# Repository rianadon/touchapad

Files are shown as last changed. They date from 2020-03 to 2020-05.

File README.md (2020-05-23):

# Touchapad

Touchapad is an touchscreen-based button pad designed to be placed outdoors and control [Home Assistant](https://home-assistant.io) devices.

This repository hosts the code used for:
 - The Arduino controlling the touchscreen
 - STL files for 3D-printed parts
 - KiCad files for the Arduino shield. You can download KiCad to export Gerber files configured to however your PCB manufacturer requires.
 - Python server for linking the Arduino touchscreen to Home Assistant and serving the configuration frontend
 - Configuration frontend source code (uses Svelte so you've got to compile it)

The Touchapad

Design and architecture information can be found at the project's [blog post](https://rianadon.github.io/blog/2020/05/23/touchapad.html).

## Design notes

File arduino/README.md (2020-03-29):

# Arduino Code

Code here is designed to run on an Arduino Leonardo (simply chosen becaue due to limited space, buying a slim USB cable for a micro-USB port was much easier than buying one for the bulky USB port of an Uno.

The excess of files is due to me having to modify the MCU and GFX libraries slim down the sketch size. They are missing a few lines of code compared to their original form. However, since they are in this repository, you don't have to install any external libraries!

## What are these Python files?

The files `corners.py` and `font.py` generate `corners.h` and `font.h` respectively. Both of these files exist because it is much easier to create anti-aliased text in Python and export it as bitmaps for the Arduino code to consume rather than try to perform the same computations on the Arduino. `corners.py` generates bitmaps for creating rectangles with rounded corners, and `font.py` generates bitmaps for a random font I found on my computer.

## Uploading

You can either upload the sketch using the Arduino IDE, or use

```bash
arduino-cli compile -u -b arduino:avr:leonardo -p /dev/ttyACM0 .
```

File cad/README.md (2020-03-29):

# Files to be 3D printed

You'll need one of each part, except for `standoff.stl` - you'll need three. They were designed to be printed in ABS, but PLA would probably work too.

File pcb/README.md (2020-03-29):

# PCB files

These files were generated using KiCad. You can use the same software to generate the gerbers and drill files, which I've omitted.

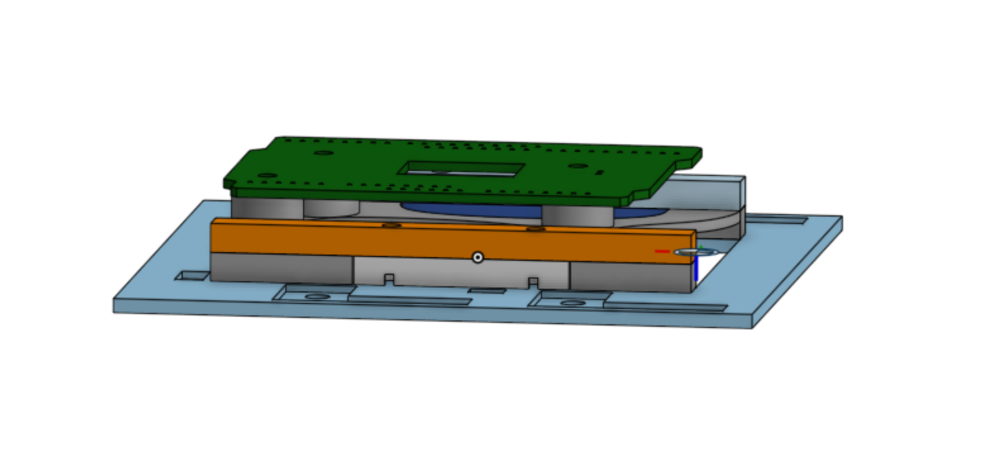
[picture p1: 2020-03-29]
cad/screenshot-2.png

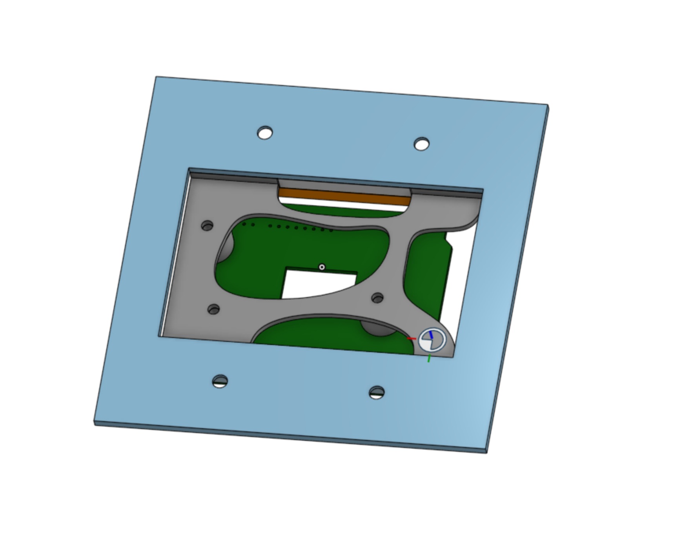
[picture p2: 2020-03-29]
cad/screenshot-1.png

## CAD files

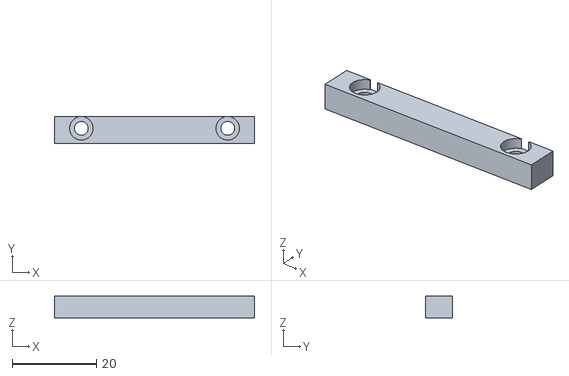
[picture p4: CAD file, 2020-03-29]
cad/holder1.stl
47.4 x 6.35 x 5.15

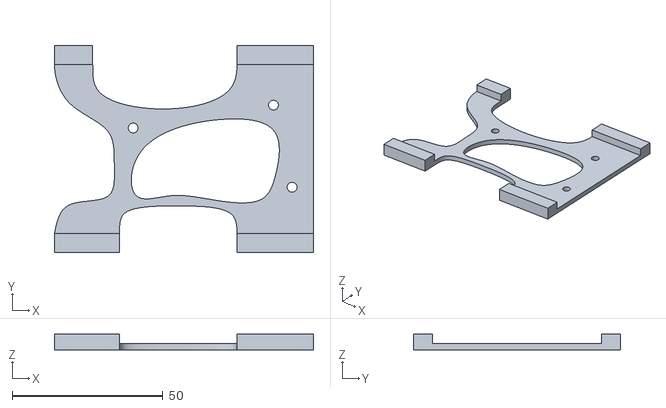
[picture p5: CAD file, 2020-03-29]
cad/arduinoholder.stl
86.0 x 68.7 x 5.15

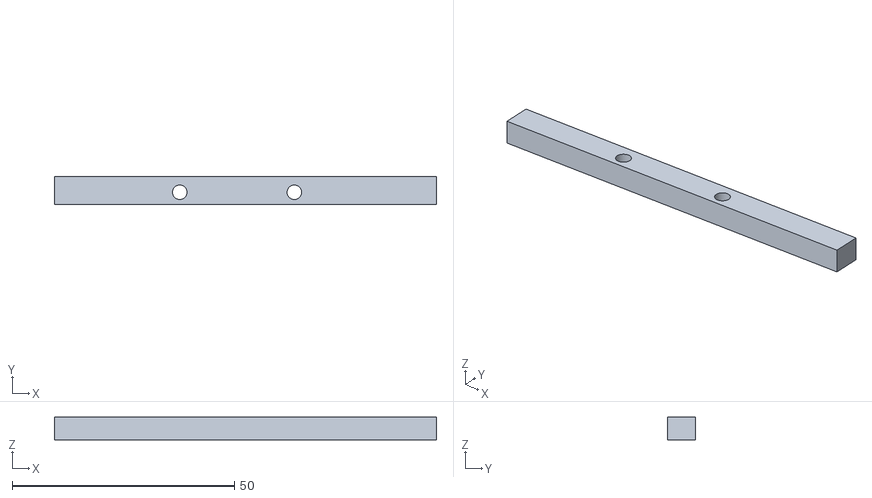
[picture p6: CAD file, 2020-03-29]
cad/holder4.stl
86.0 x 6.35 x 5.16

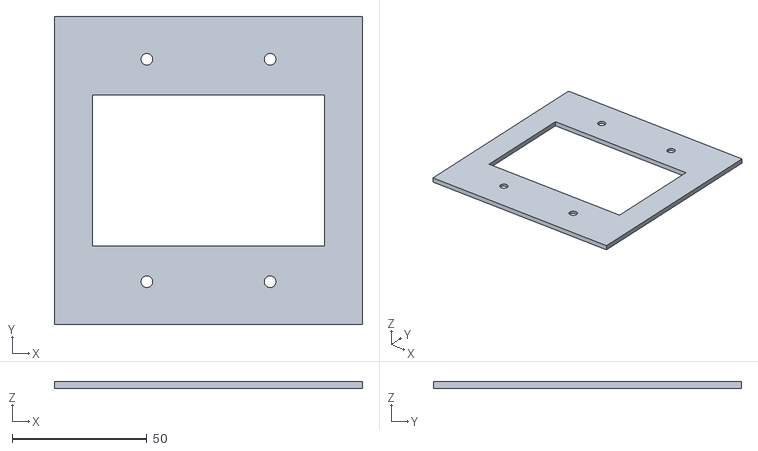
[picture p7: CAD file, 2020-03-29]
cad/cover.stl
114.3 x 114.3 x 2.50

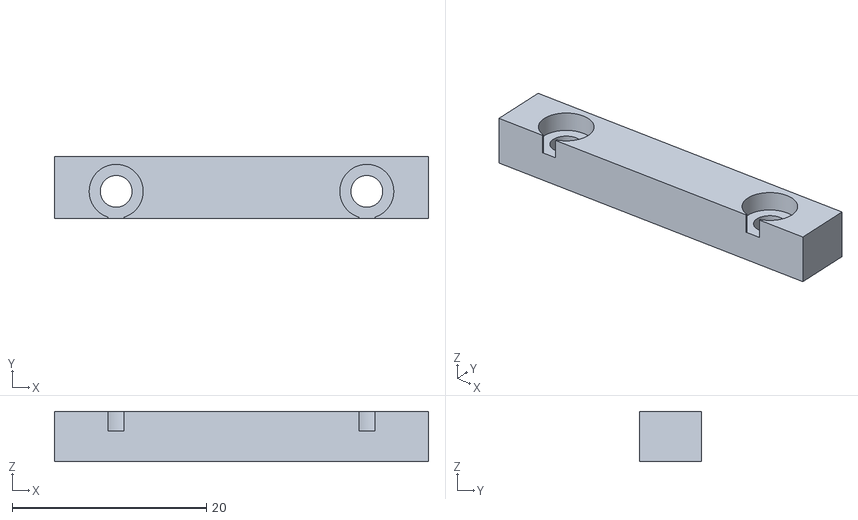
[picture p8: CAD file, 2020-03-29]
cad/holder2.stl
38.5 x 6.35 x 5.15

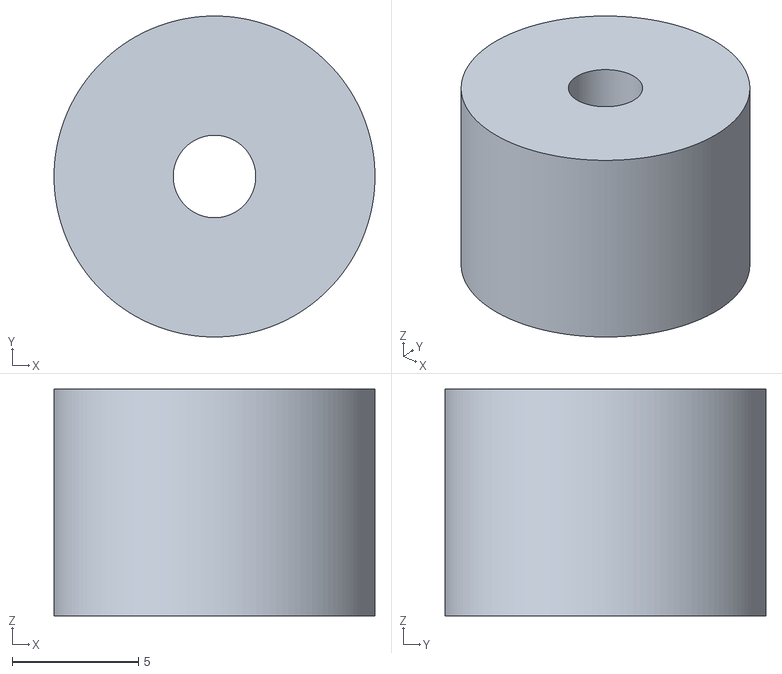
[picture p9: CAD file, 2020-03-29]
cad/standoff.stl
12.7 x 12.7 x 8.97

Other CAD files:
cad/holder3.stl

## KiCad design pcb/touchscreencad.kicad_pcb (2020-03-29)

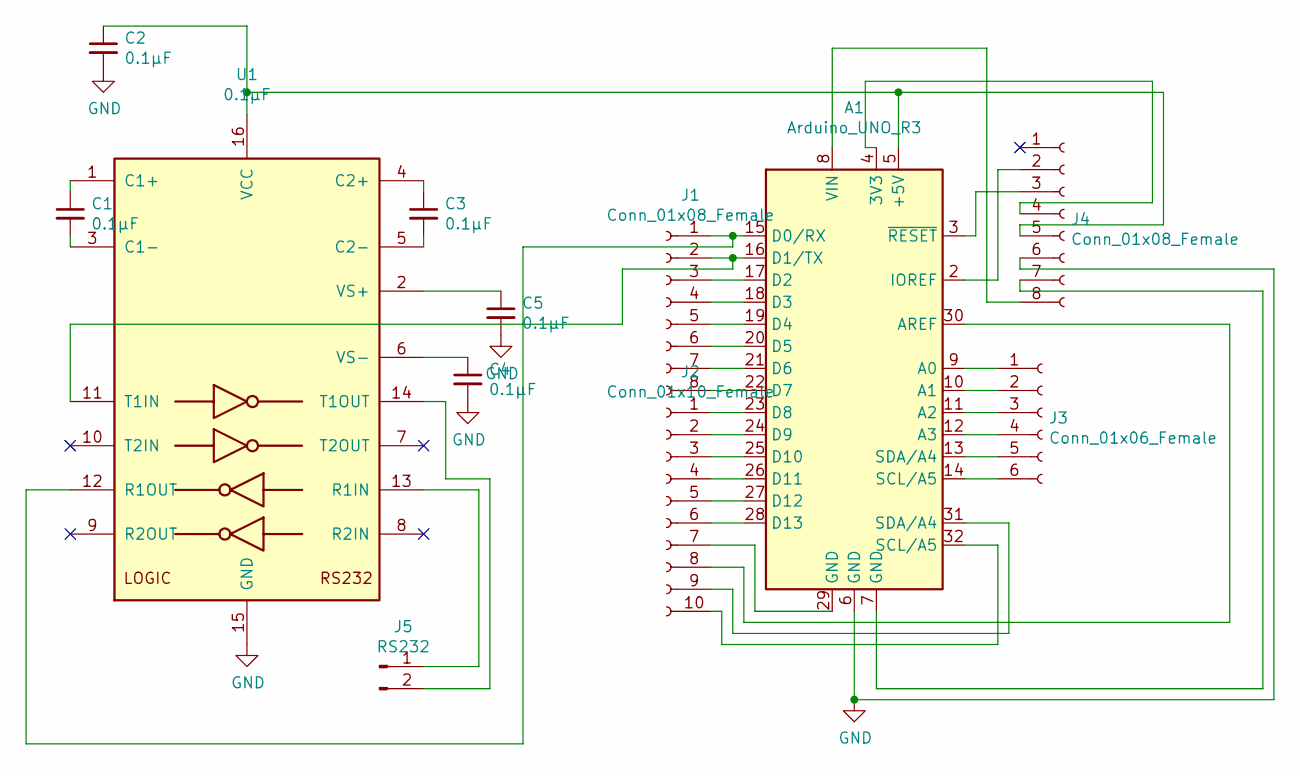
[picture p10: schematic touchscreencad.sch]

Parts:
A1: Arduino_UNO_R3
C1, C2, C3, C4, C5: 0.1μF; C_0402_1005Metric
J1: Conn_01x08_Female; PinHeader_1x08_P2.54mm_Vertical
J2: Conn_01x10_Female; PinHeader_1x10_P2.54mm_Vertical
J3: Conn_01x06_Female; PinHeader_1x06_P2.54mm_Vertical
J4: Conn_01x08_Female; PinSocket_1x08_P2.54mm_Vertical
J5: RS232; PinSocket_1x02_P2.54mm_Horizontal
U1: 0.1μF; SOIC-16_3.9x9.9mm_P1.27mm

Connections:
GND: A1.6 (GND), C2.2, C4.2, C5.2, J4.6, U1.15 (GND)
unnamed: A1.2 (IOREF), J4.2
unnamed: A1.3 (~RESET), J4.3
unnamed: A1.4 (3V3), J4.4
unnamed: A1.5 (+5V), C2.1, J4.5, U1.16 (VCC)
unnamed: A1.7 (GND), J4.7
unnamed: A1.8 (VIN), J4.8
unnamed: A1.9 (A0), J3.1
unnamed: A1.10 (A1), J3.2
unnamed: A1.11 (A2), J3.3
unnamed: A1.12 (A3), J3.4
unnamed: A1.13 (SDA/A4), J3.5
unnamed: A1.14 (SCL/A5), J3.6
unnamed: A1.15 (D0/RX), J1.1, U1.12 (R1OUT)
unnamed: A1.16 (D1/TX), J1.2, U1.11 (T1IN)
unnamed: A1.17 (D2), J1.3
unnamed: A1.18 (D3), J1.4
unnamed: A1.19 (D4), J1.5
unnamed: A1.20 (D5), J1.6
unnamed: A1.21 (D6), J1.7
unnamed: A1.22 (D7), J1.8
unnamed: A1.23 (D8), J2.1
unnamed: A1.24 (D9), J2.2
unnamed: A1.25 (D10), J2.3
unnamed: A1.26 (D11), J2.4
unnamed: A1.27 (D12), J2.5
unnamed: A1.28 (D13), J2.6
unnamed: A1.29 (GND), J2.7
unnamed: A1.30 (AREF), J2.8
unnamed: A1.31 (SDA/A4), J2.9
unnamed: A1.32 (SCL/A5), J2.10
unnamed: C1.1, U1.1 (C1+)
unnamed: C1.2, U1.3 (C1-)
unnamed: C3.1, U1.4 (C2+)
unnamed: C3.2, U1.5 (C2-)
unnamed: C4.1, U1.6 (VS-)
unnamed: C5.1, U1.2 (VS+)
unnamed: J5.1, U1.13 (R1IN)
unnamed: J5.2, U1.14 (T1OUT)

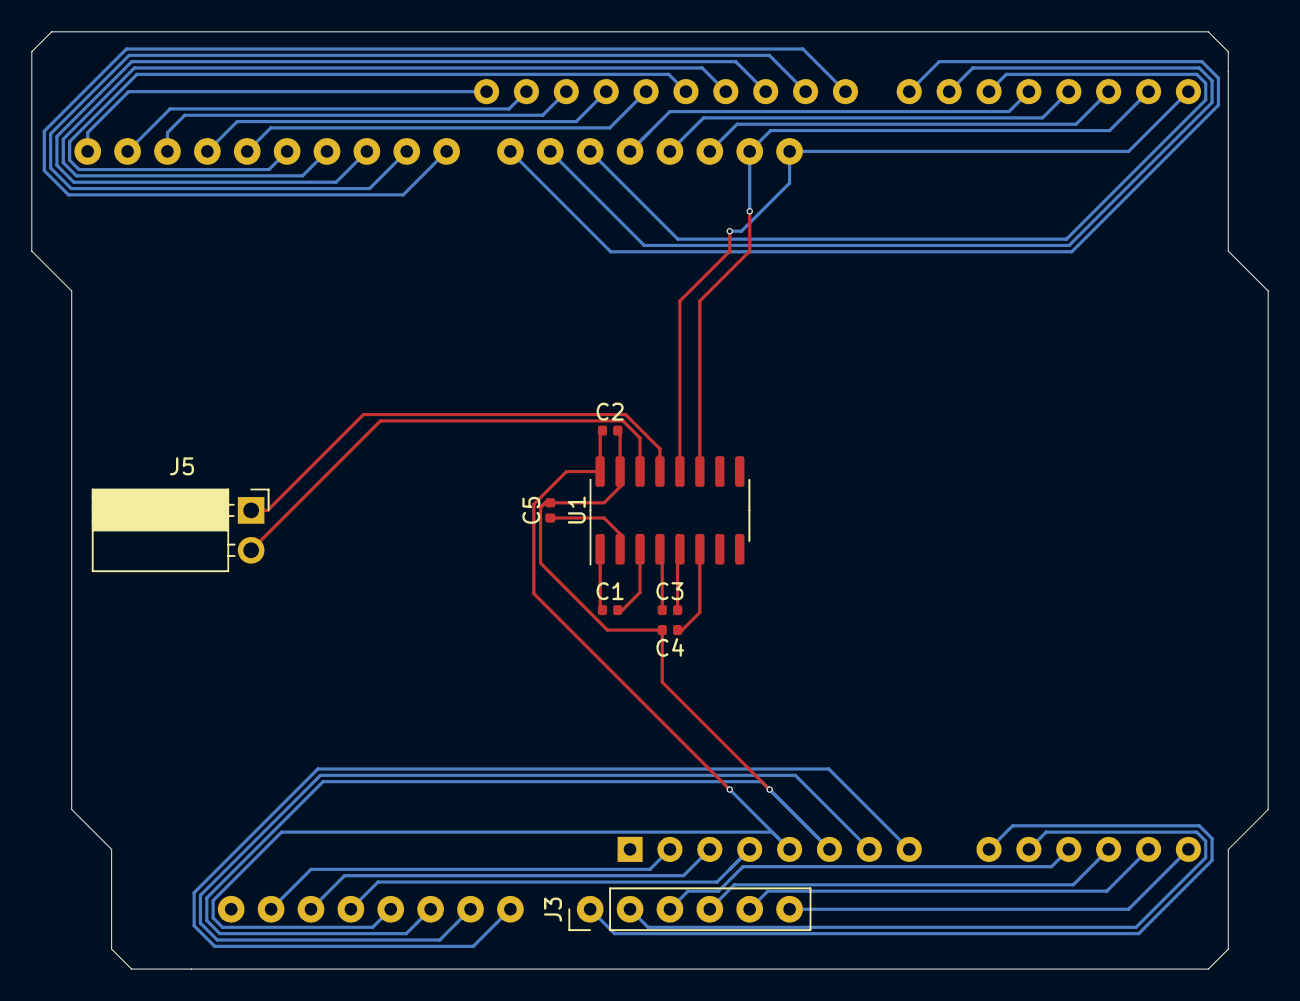
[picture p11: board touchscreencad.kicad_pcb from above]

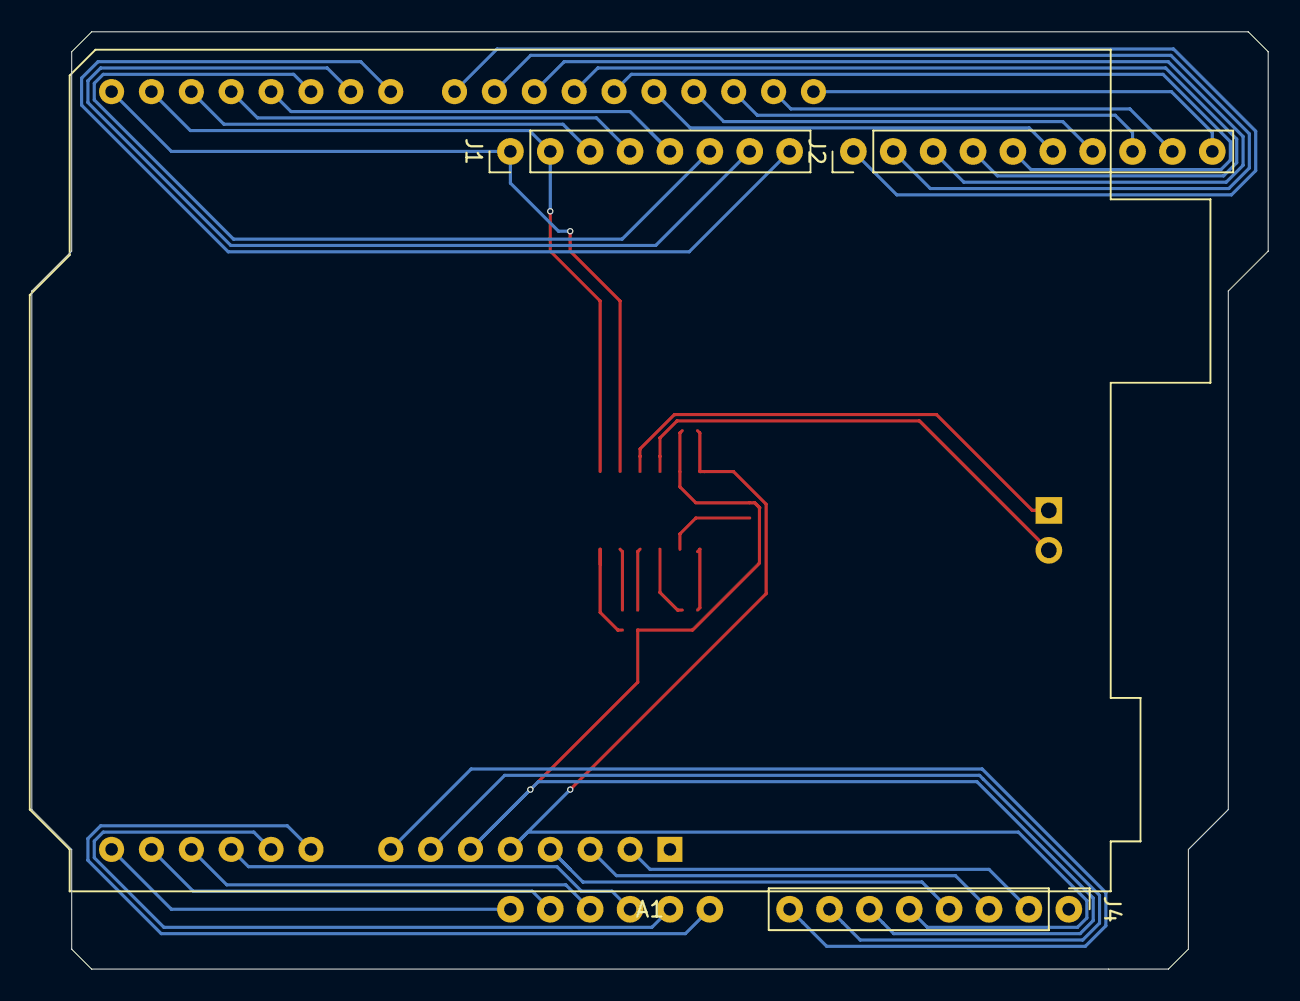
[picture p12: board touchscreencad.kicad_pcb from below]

Board: 2 copper layers, 78.7 x 59.7 mm, 12 parts (4 on the bottom side), 39 nets.

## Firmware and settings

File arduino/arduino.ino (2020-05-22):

/** Touchscreen interface

== PROTOCOL ==
All messages are sent in the following format:
X#DATA | x is a message type, # represents an optional button number,
          and DATA is data to send along with the message
Each message ends with a newline (unix-style i.e. \n). Thus, there
is a one-to-one correspondence between lines and messages.
Note: messages are also processed with 'r'.
Both messages to and from the button pad follow this protocol.

= DATA TYPES =
Button numbers are sent as a single hexadecimal digit (0 - B).
Booleans are reprsented by either 't' or 'f'. Using any other letter
will result in an error.
Strings are sent as-is.

= SENT COMMANDS =
i        | Program has started.
s#B      | Button with number # was set to the boolean B.
eMESSAGE | Error with message string message.
t#TITLE  | Inform that button with number # has title TITLE.

= RECEIVED COMMANDS =
s#B      | Set button with number # to the boolean B.
t#TITLE  | Set the title of button # to TITLE, where TITLE is a string.
q#       | Query the title of button with number #.
*/

// the regular Adafruit "TouchScreen.h" library only works on AVRs

// different mcufriend shields have Touchscreen on different pins
// and rotation.
// Run the TouchScreen_Calibr_native sketch for calibration of your shield

#include "MCUFRIEND_kbv.h"
#include "font.h"
#include "corners.h"
MCUFRIEND_kbv tft;       // hard-wired for UNO shields anyway.
#include "TouchScreen_kbv.h"
#include <EEPROM.h>

// touchscreen constants
const int XP=8,XM=A2,YP=A3,YM=9; //320x480 ID=0x9486
const int TS_LEFT=112,TS_RT=909,TS_TOP=957,TS_BOT=90;

TouchScreen_kbv ts = TouchScreen_kbv(XP, YP, XM, YM, 300);
TSPoint_kbv tp;
String command;

#define MINPRESSURE 100
#define MAXPRESSURE 1000
#define MINDURATION 50
#define MAXDURATION 3000

#define MAXTITLE 15 // Max title length

uint16_t ID, oldcolor, currentcolor;
uint8_t Orientation = 3;    //LANDSCAPE

/* uint16_t CORNER_WHITE[4][4] = { */
/*                                {0x0000, 0x2104, 0xbdf7, 0xef7d}, */
/*                                {0x2104, 0xef7d, 0xffff, 0xffff}, */
/*                                {0xbdf7, 0xffff, 0xffff, 0xffff}, */
/*                                {0xef7d, 0xffff, 0xffff, 0xffff}, */
/* }; */

/* uint16_t CORNER_GREY[4][4] = { */
/*                               {0x0000, 0x0000, 0x10a2, 0x2b2b}, */
/*                               {0x0000, 0x18e3, 0x39c7, 0x39c7}, */
/*                               {0x10a2, 0x39c7, 0x39c7, 0x39c7}, */
/*                               {0x2b2b, 0x39c7, 0x39c7, 0x39c7}, */
/* }; */

/* uint16_t CORNER_BLACK_HG[4][4] = { */
/*                               {0xffff, 0xffff, 0xdefb, 0x4208}, */
/*                               {0xffff, 0xdefb, 0x0000, 0x0000}, */
/*                               {0xdefb, 0x0000, 0x0000, 0x0000}, */
/*                               {0x4208, 0x0000, 0x0000, 0x0000}, */
/* }; */

/* uint16_t CORNER_BLACK_LG[2][2] = { */
/*                             {0xbdd7, 0x5acb}, */
/*                             {0x5acb, 0x4208}, */
/* }; */
/* uint16_t CORNER_BLACK_SM[1][1] = { */
/*                             {0xa514}, */
/* }; */

char titles[12][MAXTITLE];
boolean states[12] = {false, true, false, false, false, true, false, false, false, false, true, false};

#define BLACK   0x0000
#define WHITE   0xffff
/* #define GREY    0x39c7 */
/* #define DKGREY  0x4208 */
/* #define LTGREY  0xbdf7 // 0xef7d */

#define RED      0x9186
#define GREEN    0x0788
#define CYAN     0x07FF
#define MAGENTA  0xF81F
#define YELLOW   0xFFE0

#define BOXWIDTH 160
#define BOXHEIGHT 80
#define BOXPAD 10

#define BUTWIDTH BOXWIDTH-2*BOXPAD
#define BUTHEIGHT BOXHEIGHT-2*BOXPAD

void drawButtons() {
    int titlei = 0;
    for (int i = BOXPAD; i < tft.width(); i += BOXWIDTH) {
        for (int j = BOXPAD; j < tft.height(); j += BOXHEIGHT) {
            button(i, j, titlei++);
        }
    }
}

void setup() {
    tft.reset();
    ID = tft.readID();
    tft.begin(ID);
    tft.setRotation(Orientation);
    tft.fillScreen(BLACK);

    Serial.begin(9600);
    Serial.println('i');
    for (int i = 0; i < 12; i++) {
        for (int j = 0; j < MAXTITLE; j++) {
            char c = EEPROM.read(i * MAXTITLE + j);
            titles[i][j] = c;
            if (c == '\0') break;
        }
    }

    drawButtons();
}

int xbox = -1;
int ybox = -1;
unsigned long lastPress = -1;

void touch() {
    int title = xbox*4 + ybox;
    states[title] = !states[title];
    Serial.print('s');
    Serial.print(title, HEX);
    Serial.println(states[title] ? 't' : 'f');
    Serial.flush();

    int butx = xbox*BOXWIDTH+BOXPAD;
    int buty = ybox*BOXHEIGHT+BOXPAD;
    if (states[title]) { // Enabling
        for (int step = 0; step <= 255; step += 51) {
            uint16_t col = (step/8 << 11) + (step/4 << 5) + (step/8);
            tft.fillRect(butx+4, buty+4, BUTWIDTH-8, BUTHEIGHT-8, col);
            if (step == 0) buttonTitle(butx, buty, xbox*4 + ybox, false);
        }
        roundedRectangle(butx, buty, BUTWIDTH, BUTHEIGHT,
                         (uint16_t *)CORNER_WHITE, 4, WHITE);
    } else { //Disabling
        for (int step = 255; step > 0; step -= 51) {
            uint16_t col = (step/8 << 11) + (step/4 << 5) + (step/8);
            tft.fillRect(butx+4, buty+4, BUTWIDTH-8, BUTHEIGHT-8, col);
            if (step == 255) buttonTitle(butx, buty, xbox*4 + ybox, true);
        }
        roundedRectangle(butx, buty, BUTWIDTH, BUTHEIGHT,
                         (uint16_t *)CORNER_LTGREY, 4, LTGREY);
        roundedRectangle(butx+4, buty+4, BUTWIDTH-8, BUTHEIGHT-8,
                         (uint16_t *)CORNER_BLACK_HG, 4, BLACK);
    }
    buttonExtra(butx, buty, title);
    buttonTitle(butx, buty, title, states[title]);

    // Send a second time just to make sure it's received
    Serial.print('s');
    Serial.print(title, HEX);
    Serial.println(states[title] ? 't' : 'f');
    Serial.flush();
}

void processCommand() {
    switch (command[0]) {
    case 's': {
        int title = hexToButton(command[1]);
        if (title < 0) break;
        if (command[2] != 't' && command[2] != 'f') {
            Serial.println("eInvalid boolean");
            break;
        }
        boolean newState = (command[2] == 't');
        if (states[title] != newState) {
          states[title] = newState;
          autoButton(title);
        }
        break;
    }
    case 't': {
        int title = hexToButton(command[1]);
        if (title < 0) break;
        command.substring(2).toCharArray(titles[title], MAXTITLE);
        int i;
        for (i = 0; i < MAXTITLE && titles[title][i] != '\0'; i++) {
            EEPROM.write(title * MAXTITLE + i, titles[title][i]);
        }
        EEPROM.write(title * MAXTITLE + i, '\0');
        autoButton(title);
        break;
    }
    case 'q': {
        int title = hexToButton(command[1]);
        if (title < 0) break;
        Serial.print('t');
        Serial.print(title, HEX);
        Serial.println(titles[title]);
        break;
    }
    default:
        Serial.print("eUnkown command \"");
        Serial.print(command[0]);
        Serial.print("\" in \"");
        Serial.print(command);
        Serial.println("\"");
    }
    Serial.flush();
}

void loop()
{
    if (Serial.available()) {
        char r = Serial.read();
        if (r == '\n' || r == '\r') {
            if (command.length() > 0) processCommand();
            command = "";
        } else {
            command += r;
        }
    }

    uint16_t xpos, ypos;  //screen coordinates
    tp = ts.getPoint();   //tp.x, tp.y are ADC values

    // if Sharing pins, you'll need to fix the directions of the touchscreen pins
    pinMode(XM, OUTPUT);
    pinMode(YP, OUTPUT);
    if (tp.z > MINPRESSURE && tp.z < MAXPRESSURE) {
            // most mcufriend have touch (with icons) that extends below the TFT
        // screens without icons need to reserve a space for "erase"
        // scale the ADC values from ts.getPoint() to screen values e.g. 0-239
        //
        // Calibration is true for PORTRAIT. tp.y is always long dimension
        // map to your current pixel orientation
        switch (Orientation) {
            case 0:
                xpos = map(tp.x, TS_LEFT, TS_RT, 0, tft.width());
                ypos = map(tp.y, TS_TOP, TS_BOT, 0, tft.height());
                break;
            case 1:
                xpos = map(tp.y, TS_TOP, TS_BOT, 0, tft.width());
                ypos = map(tp.x, TS_RT, TS_LEFT, 0, tft.height());
                break;
            case 2:
                xpos = map(tp.x, TS_RT, TS_LEFT, 0, tft.width());
                ypos = map(tp.y, TS_BOT, TS_TOP, 0, tft.height());
                break;
            case 3:
                xpos = map(tp.y, TS_BOT, TS_TOP, 0, tft.width());
                ypos = map(tp.x, TS_LEFT, TS_RT, 0, tft.height());
                break;
        }

        int newx = xpos / BOXWIDTH;
        int newy = ypos / BOXHEIGHT;
        if (newx >= 3 || newy >= 4) return;

        if (xpos / BOXWIDTH != xbox || ypos / BOXHEIGHT != ybox) {
            xbox = xpos / BOXWIDTH;
            ybox = ypos / BOXHEIGHT;
            lastPress = millis();
        }

        /* unsigned long duration = millis() - lastPress; */
        /* if (duration > MINDURATION && duration < MAXDURATION) { */
        touch();
        /* } */
    }
}

void autoButton(int title) {
    int butx = title / 4;
    int buty = title % 4;
    button(butx * BOXWIDTH + BOXPAD, buty * BOXHEIGHT + BOXPAD, title);
}

void button(uint16_t x, uint16_t y, int title) {
    roundedRectangle(x+3, y+6, BUTWIDTH, BUTHEIGHT,
                     (uint16_t *)CORNER_GREY, 4, GREY);
    roundedRectangle(x, y, BUTWIDTH, BUTHEIGHT,
                     (uint16_t *)(states[title] ? CORNER_WHITE : CORNER_LTGREY), 4, states[title] ? WHITE : LTGREY);
    if (!states[title]) {
        roundedRectangle(x+4, y+4, BUTWIDTH-8, BUTHEIGHT-8,
                         (uint16_t *)CORNER_BLACK_HG, 4, BLACK);
    }
    buttonExtra(x, y, title);
    /* tft.setTextColor(WHITE); */
    /* tft.setCursor(x+23, y + 22); */
    /* tft.setTextSize(2); */
    /* tft.println("A button"); */
    buttonTitle(x, y, title, states[title]);
}

void buttonExtra(uint16_t x, uint16_t y, int title) {
    if (states[title]) {
        roundedRectangle(x+8, y+2, BUTWIDTH-16, 3, (uint16_t *)CORNER_GREEN_SM, 1, GREEN);
        roundedRectangle(x+5, y+54, BUTWIDTH-10, 4, (uint16_t *)CORNER_GREEN_LG, 2, GREEN);
    } else {
        roundedRectangle(x+8, y+2, BUTWIDTH-16, 3, (uint16_t *)CORNER_BLACK_SM, 1, DKGREY);
        roundedRectangle(x+5, y+54, BUTWIDTH-10, 4, (uint16_t *)CORNER_BLACK_LG, 2, DKGREY);
    }
}

void buttonTitle(uint16_t x, uint16_t y, int title, boolean inverse) {
    drawString(titles[title], x+70 - textWidth(titles[title])/2, y + 38, inverse);
}

/** Draw an wxh image at (x,y) given directons */
void drawPixmap(uint16_t *image, uint16_t x, uint16_t y, uint16_t w, uint16_t h, boolean xfor, boolean yfor) {
    for (int i = 0; i < w; i++) {
        for (int j = 0; j < h; j++) {
            if (xfor) {
                if (yfor) tft.drawPixel(x+i, y+j, *(image + j*h + i));
                else      tft.drawPixel(x+i, y+h-1-j, *(image + j*h + i));
            } else {
                if (yfor) tft.drawPixel(x+w-1-i, y+j, *(image + j*h + i));
                else      tft.drawPixel(x+w-1-i, y+h-1-j, *(image + j*h + i));
            }
        }
    }
}

/** Draw a rounded rectangle bounded by (x, y, x+w, y+h) */
void roundedRectangle(uint16_t x, uint16_t y, uint16_t w, uint16_t h, uint16_t *corners, uint16_t cw, uint16_t fill) {
    // Radius is fixed to 3 pixels.
    drawPixmap(corners, x, y, cw, cw, true, true);
    tft.fillRect(x+cw, y, w-cw*2, cw, fill);
    drawPixmap(corners, x+w-cw, y, cw, cw, false, true);
    tft.fillRect(x, y+cw, w, h-cw, fill);
    drawPixmap(corners, x, y+h-cw, cw, cw, true, false);
    tft.fillRect(x+cw, y+h-cw, w-cw*2, cw, fill);
    drawPixmap(corners, x+w-cw, y+h-cw, cw, cw, false, false);
}

/** Draw a character */
uint16_t drawChar(char c, uint16_t x, uint16_t y, boolean inverse) {
    int hindex = (c - 32) * 5;
    int rows = FONTHEAD[hindex];
    int width = FONTHEAD[hindex+1];
    int left = FONTHEAD[hindex+2];
    int top = FONTHEAD[hindex+3];
    int advance = FONTHEAD[hindex+4];

    int datindex = pgm_read_word_near(FONTIDX + c - 32);
    int mode = 0;
    for (int i = 0; i < rows; i++) {
        for (int j = 0; j < width; j++) {
            int dat = pgm_read_word_near(FONTDATA + datindex);
            int color;
            if (mode == 0) {
                color = dat >> 10;
            } else if (mode == 1) {
                color = (dat >> 5) & 31;
            } else {
                color = dat & 31;
            }
            if (inverse) color = 31 - color;
            uint16_t rgb = (color << 11) + ((color * 2) << 5) + color;
            tft.drawPixel(x+j+left, y+i-top, rgb);
            mode++;
            if (mode == 3) {
                mode = 0;
                datindex++;
            }
        }
    }
    return advance;
}

void drawString(String str, uint16_t x, uint16_t y, boolean inverse) {
    for (int i = 0; i < MAXTITLE && str[i] != '\0'; i++) {
        x += drawChar(str[i], x, y, inverse);
    }
}

int textWidth(String str) {
    int w = 0;
    for (int i = 0; i < MAXTITLE && str[i] != '\0'; i++) {
        int hindex = (str[i] - 32) * 5;
        int advance = FONTHEAD[hindex+4];
        w += advance;
    }
    return w;
}

/** Converts hex char --> integer */
int ctoi(char c) {
    if (c >= '0' && c <= '9') {
        return c - '0';
    } else if (c >= 'A' && c <= 'F') {
        return c - 'A' + 10;
    } else if (c >= 'a' && c <= 'f') {
        return c - 'a' + 10;
    }
    return -1;
}

int hexToButton(char c) {
    int title = ctoi(command[1]);
    if (title < 0) {
        Serial.println("eInvalid hex character " + command[1]);
        return -1;
    } else if (title > 11) {
        Serial.println("eOnly 12 buttons (0 - 11) supported");
        return -2;
    }
    return title;
}

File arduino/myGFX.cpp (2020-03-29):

/*
This is the core graphics library for all our displays, providing a common
set of graphics primitives (points, lines, circles, etc.).  It needs to be
paired with a hardware-specific library for each display device we carry
(to handle the lower-level functions).

Adafruit invests time and resources providing this open source code, please
support Adafruit & open-source hardware by purchasing products from Adafruit!

Copyright (c) 2013 Adafruit Industries.  All rights reserved.

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
- Redistributions of source code must retain the above copyright notice,
  this list of conditions and the following disclaimer.
- Redistributions in binary form must reproduce the above copyright notice,
  this list of conditions and the following disclaimer in the documentation
  and/or other materials provided with the distribution.

THIS SOFTWARE IS PROVIDED BY THE COPYRIGHT HOLDERS AND CONTRIBUTORS "AS IS"
AND ANY EXPRESS OR IMPLIED WARRANTIES, INCLUDING, BUT NOT LIMITED TO, THE
IMPLIED WARRANTIES OF MERCHANTABILITY AND FITNESS FOR A PARTICULAR PURPOSE
ARE DISCLAIMED. IN NO EVENT SHALL THE COPYRIGHT HOLDER OR CONTRIBUTORS BE
LIABLE FOR ANY DIRECT, INDIRECT, INCIDENTAL, SPECIAL, EXEMPLARY, OR
CONSEQUENTIAL DAMAGES (INCLUDING, BUT NOT LIMITED TO, PROCUREMENT OF
SUBSTITUTE GOODS OR SERVICES; LOSS OF USE, DATA, OR PROFITS; OR BUSINESS
INTERRUPTION) HOWEVER CAUSED AND ON ANY THEORY OF LIABILITY, WHETHER IN
CONTRACT, STRICT LIABILITY, OR TORT (INCLUDING NEGLIGENCE OR OTHERWISE)
ARISING IN ANY WAY OUT OF THE USE OF THIS SOFTWARE, EVEN IF ADVISED OF THE
POSSIBILITY OF SUCH DAMAGE.
 */

#include "myGFX.h"
#ifdef __AVR__
  #include <avr/pgmspace.h>
#elif defined(ESP8266) || defined(ESP32)
  #include <pgmspace.h>
#endif

// Many (but maybe not all) non-AVR board installs define macros
// for compatibility with existing PROGMEM-reading AVR code.
// Do our own checks and defines here for good measure...

#ifndef pgm_read_byte
 #define pgm_read_byte(addr) (*(const unsigned char *)(addr))
#endif
#ifndef pgm_read_word
 #define pgm_read_word(addr) (*(const unsigned short *)(addr))
#endif
#ifndef pgm_read_dword
 #define pgm_read_dword(addr) (*(const unsigned long *)(addr))
#endif

// Pointers are a peculiar case...typically 16-bit on AVR boards,
// 32 bits elsewhere.  Try to accommodate both...

#if !defined(__INT_MAX__) || (__INT_MAX__ > 0xFFFF)
 #define pgm_read_pointer(addr) ((void *)pgm_read_dword(addr))
#else
 #define pgm_read_pointer(addr) ((void *)pgm_read_word(addr))
#endif

#ifndef min
#define min(a,b) (((a) < (b)) ? (a) : (b))
#endif

#ifndef _swap_int16_t
#define _swap_int16_t(a, b) { int16_t t = a; a = b; b = t; }
#endif

/**************************************************************************/
/*!
   @brief    Instatiate a GFX context for graphics! Can only be done by a superclass
   @param    w   Display width, in pixels
   @param    h   Display height, in pixels
*/
/**************************************************************************/
myGFX::myGFX(int16_t w, int16_t h):
WIDTH(w), HEIGHT(h)
{
    _width    = WIDTH;
    _height   = HEIGHT;
    rotation  = 0;
    cursor_y  = cursor_x    = 0;
    textsize  = 1;
    textcolor = textbgcolor = 0xFFFF;
    wrap      = true;
    _cp437    = false;
}

/**************************************************************************/
/*!
   @brief    Write a line.  Bresenham's algorithm - thx wikpedia
    @param    x0  Start point x coordinate
    @param    y0  Start point y coordinate
    @param    x1  End point x coordinate
    @param    y1  End point y coordinate
    @param    color 16-bit 5-6-5 Color to draw with
*/
/**************************************************************************/
void myGFX::writeLine(int16_t x0, int16_t y0, int16_t x1, int16_t y1,
        uint16_t color) {
    int16_t steep = abs(y1 - y0) > abs(x1 - x0);
    if (steep) {
        _swap_int16_t(x0, y0);
        _swap_int16_t(x1, y1);
    }

    if (x0 > x1) {
        _swap_int16_t(x0, x1);
        _swap_int16_t(y0, y1);
    }

    int16_t dx, dy;
    dx = x1 - x0;
    dy = abs(y1 - y0);

    int16_t err = dx / 2;
    int16_t ystep;

    if (y0 < y1) {
        ystep = 1;
    } else {
        ystep = -1;
    }

    for (; x0<=x1; x0++) {
        if (steep) {
            writePixel(y0, x0, color);
        } else {
            writePixel(x0, y0, color);
        }
        err -= dy;
        if (err < 0) {
            y0 += ystep;
            err += dx;
        }
    }
}

/**************************************************************************/
/*!
   @brief    Start a display-writing routine, overwrite in subclasses.
*/
/**************************************************************************/
void myGFX::startWrite(){
}

/**************************************************************************/
/*!
   @brief    Write a pixel, overwrite in subclasses if startWrite is defined!
    @param   x   x coordinate
    @param   y   y coordinate
   @param    color 16-bit 5-6-5 Color to fill with
*/
/**************************************************************************/
void myGFX::writePixel(int16_t x, int16_t y, uint16_t color){
    drawPixel(x, y, color);
}

/**************************************************************************/
/*!
   @brief    Write a perfectly vertical line, overwrite in subclasses if startWrite is defined!
    @param    x   Top-most x coordinate
    @param    y   Top-most y coordinate
    @param    h   Height in pixels
   @param    color 16-bit 5-6-5 Color to fill with
*/
/**************************************************************************/
void myGFX::writeFastVLine(int16_t x, int16_t y,
        int16_t h, uint16_t color) {
    // Overwrite in subclasses if startWrite is defined!
    // Can be just writeLine(x, y, x, y+h-1, color);
    // or writeFillRect(x, y, 1, h, color);
    drawFastVLine(x, y, h, color);
}

/**************************************************************************/
/*!
   @brief    Write a perfectly horizontal line, overwrite in subclasses if startWrite is defined!
    @param    x   Left-most x coordinate
    @param    y   Left-most y coordinate
    @param    w   Width in pixels
   @param    color 16-bit 5-6-5 Color to fill with
*/
/**************************************************************************/
void myGFX::writeFastHLine(int16_t x, int16_t y,
        int16_t w, uint16_t color) {
    // Overwrite in subclasses if startWrite is defined!
    // Example: writeLine(x, y, x+w-1, y, color);
    // or writeFillRect(x, y, w, 1, color);
    drawFastHLine(x, y, w, color);
}
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

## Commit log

2020-03-29 Only 99 bugfixes to go
    [arduinoholder.stl, cover.stl, holder1.stl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]
2020-03-29 Add keypress listeners for touch buttons
2020-05-22 Only redraw display when a button's state changes
